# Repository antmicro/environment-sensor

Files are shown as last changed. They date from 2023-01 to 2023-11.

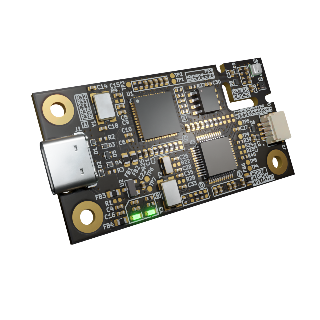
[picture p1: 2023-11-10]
assets/previews/leftT_thumbnail.png

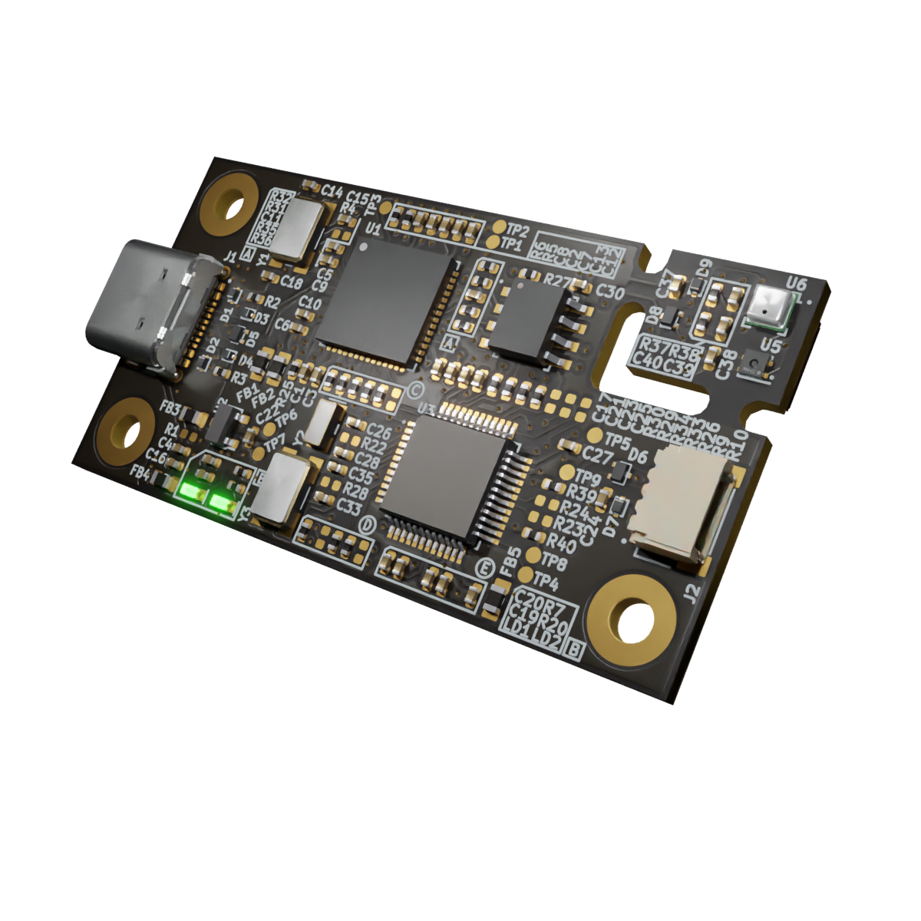
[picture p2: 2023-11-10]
assets/previews/rightT.webp

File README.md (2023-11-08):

# Environment sensor board

Copyright (c) 2023 [Antmicro](https://www.antmicro.com)

Visualization

## Overview

This project contains open hardware design files for an environment sensor board with temperature, pressure and humidity sensors.
These sensors are placed on a separated island in the PCB corner, which can be easily broken out from the main board and connected to it via provided connectors with a cable.
The design files were prepared in KiCad 6.x.

## Key features

* 50.00 mm X 26.50 mm PCB size
* USB-C Connector for data and power
* STM32G474CET6 host MCU
* 128kB external FeRAM 
* FTDI FT4232H USB - JTAG/I2C/UART converter
* SHT45 temperature + humidity sensor:

	* Typ. relative humidity accuracy ±1% RH
	* Operating relative humidity range 0 - 100% RH
	* Typ. temperature accuracy ±0.1 °C
	* Operating temperature range (-40) - (+125) °C
	
* BME280 temperature + humidity + pressure sensor:
	* Typ. relative humidity accuracy ±3% RH
	* Operating relative humidity range 10 - 100% RH
	* Typ. temperature accuracy ±1 °C
	* Operating temperature range (-40) - (+85) °C
	* Typ. pressure accuracy ±1 hPa
	* Operating pressure range 300 - 1100 hPa
	
* I2C connectors
* RTC battery backup

## I2C Address map (7-bit)
* FeRAM: 0x50 + A16 (optional)
* SHT45: 0x44
* BME280: 0x76

## Project structure

The main directory contains KiCad PCB project files, a LICENSE, and a README.
The remaining files are stored in the following directories:

* `img` - contains graphics for this README
* `assets` - contains visual assets for showcasing this design on [Open Hardware Portal](https://openhardware.antmicro.com)

## Licensing

This project is published under the [Apache-2.0](LICENSE) license.

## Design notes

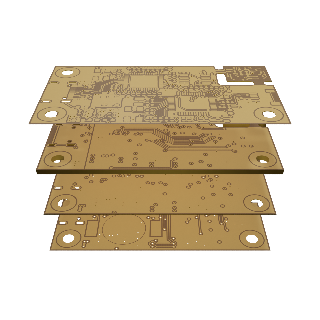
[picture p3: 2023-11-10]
assets/previews/layer1_thumbnail.webp

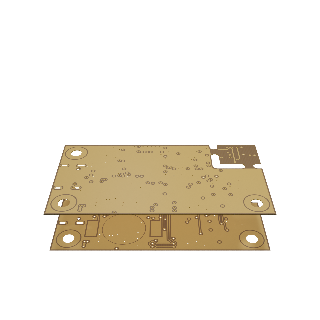
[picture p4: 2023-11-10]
assets/previews/layer3_thumbnail.webp

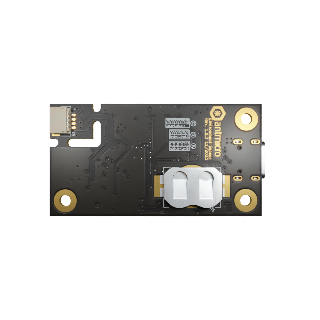
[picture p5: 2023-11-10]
assets/previews/orthoB_thumbnail.webp

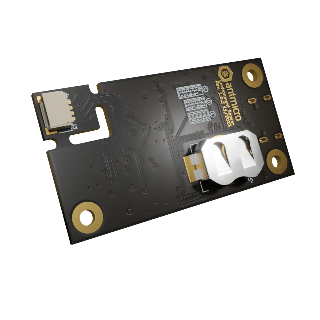
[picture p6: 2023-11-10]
assets/previews/leftB_thumbnail.png

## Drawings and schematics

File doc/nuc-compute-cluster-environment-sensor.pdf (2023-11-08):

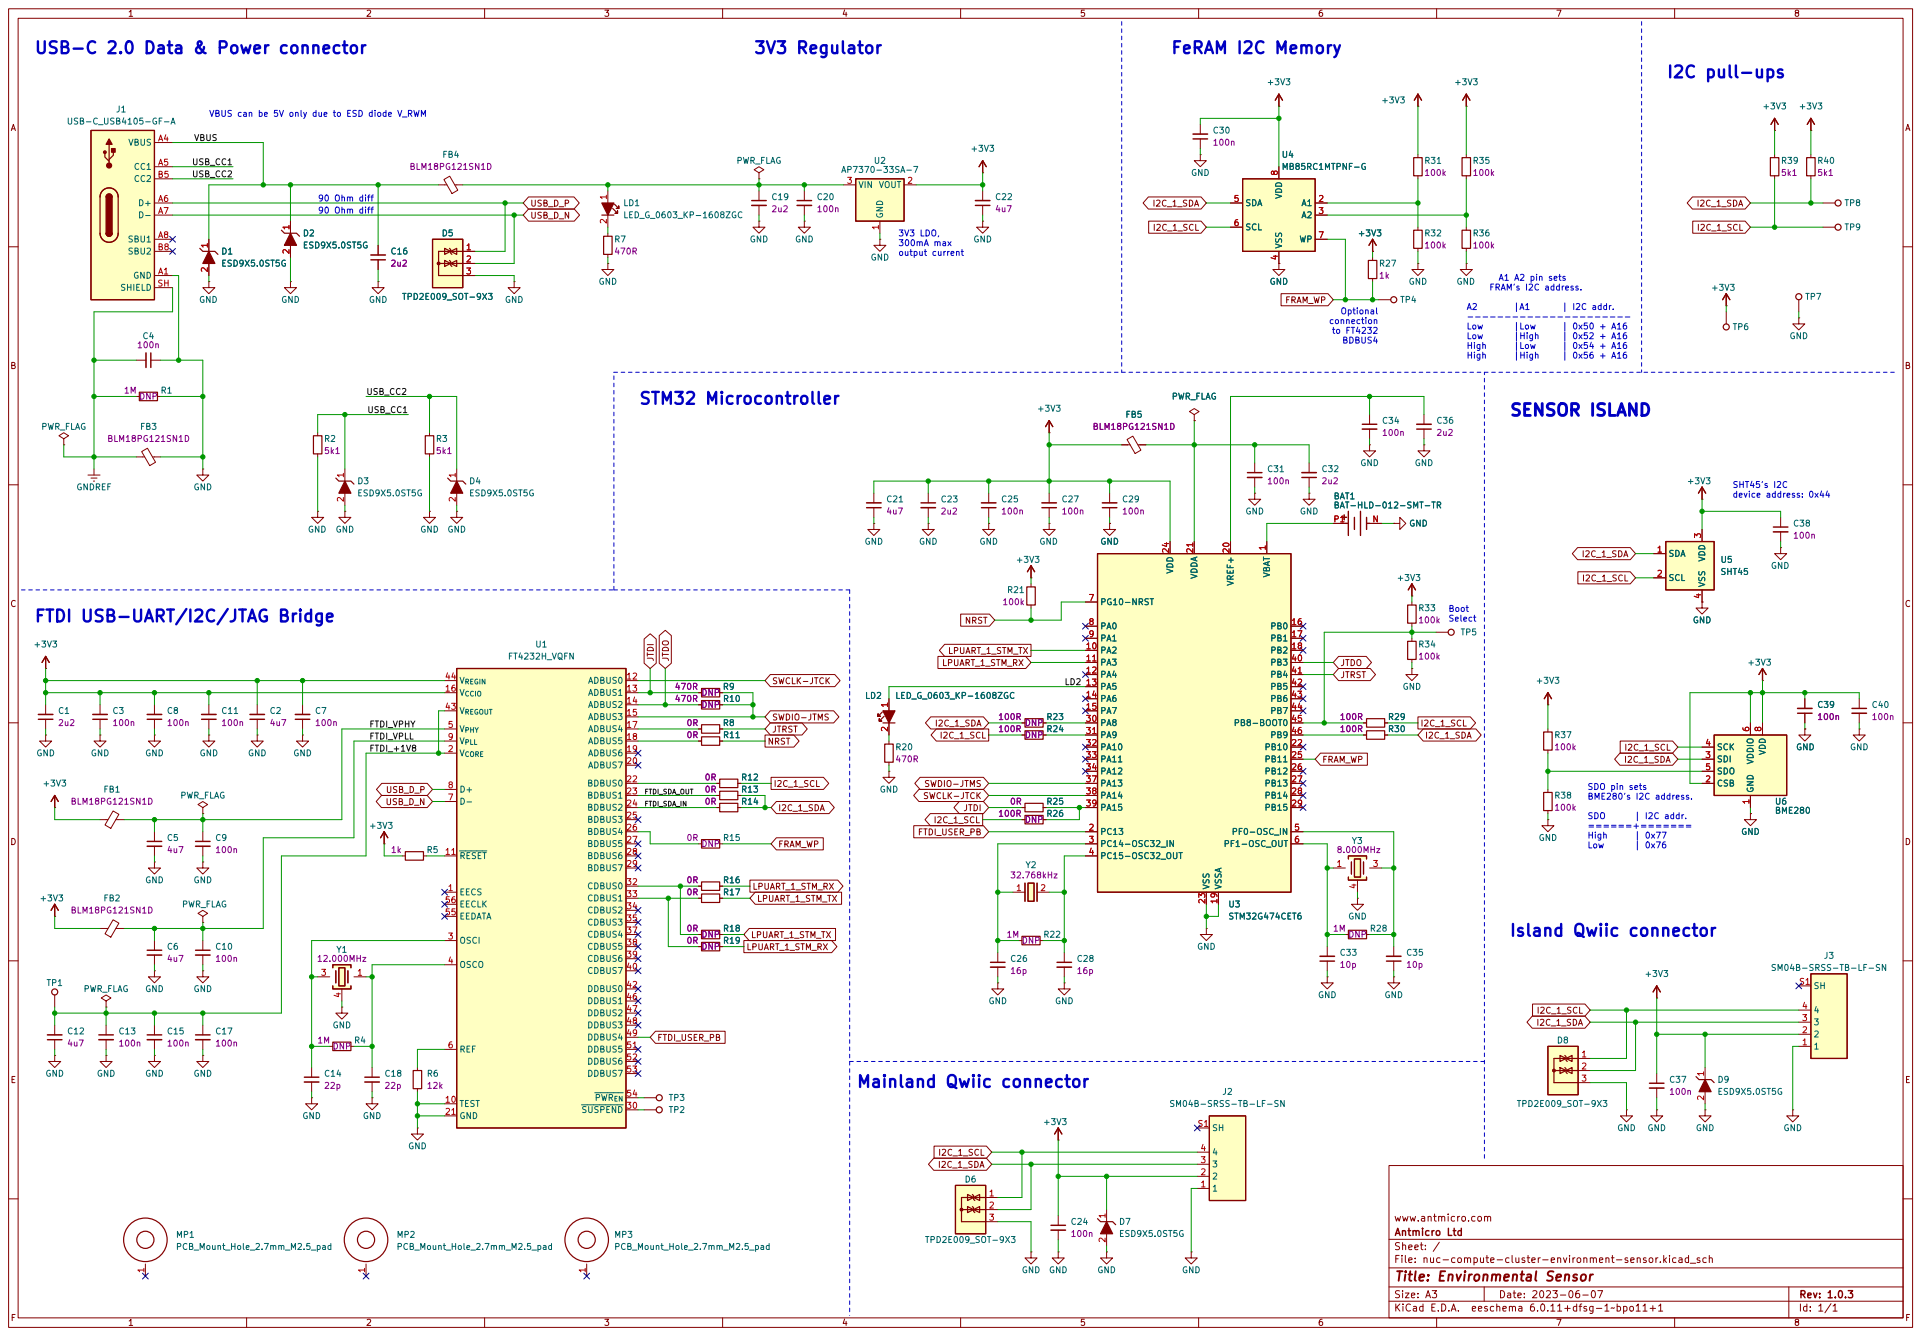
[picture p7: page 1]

VBUS can be 5V only due to ESD diode V_RWM

BAT1 BAT-HLD-012-SMT-TR

J3 SM04B-SRSS-TB-LF-SN

J2 SM04B-SRSS-TB-LF-SN

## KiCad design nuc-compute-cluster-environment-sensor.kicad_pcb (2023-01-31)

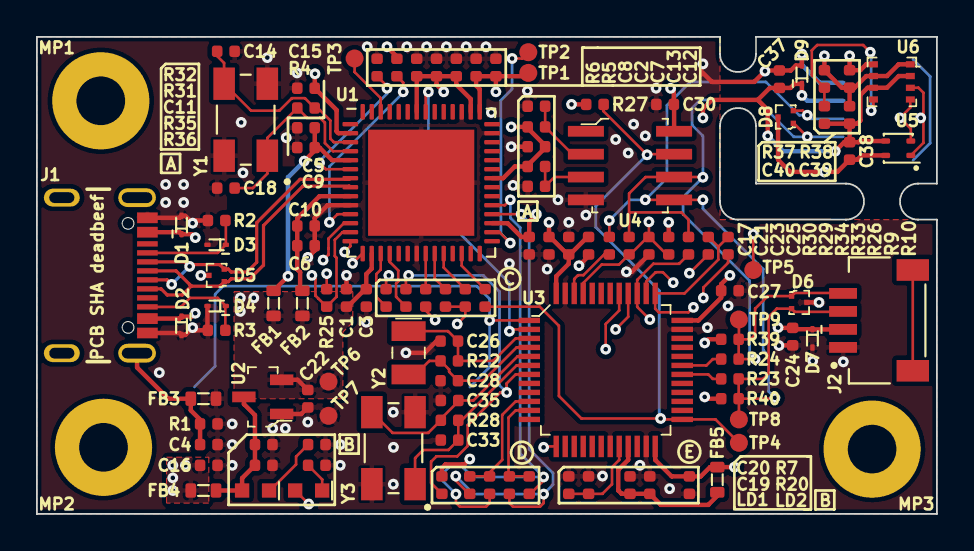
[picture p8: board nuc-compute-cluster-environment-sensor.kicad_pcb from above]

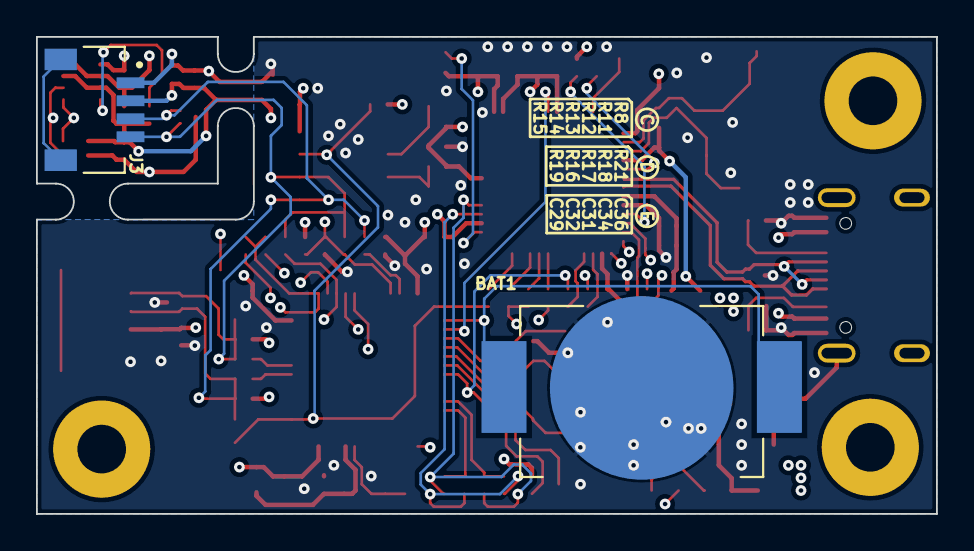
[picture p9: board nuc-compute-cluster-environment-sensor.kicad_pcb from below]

Board: 4 copper layers, 50.0 x 26.5 mm, 121 parts (2 on the bottom side), 56 nets.

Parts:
BAT1: BAT-HLD-012-SMT-TR; BAT_BAT-HLD-012-SMT-TR
C1, C16, C19, C23, C32, C36: C_2u2_0402; 0402-cap
C2, C5, C6, C12, C21, C22: C_4u7_0402; 0402-cap
C3, C4, C7, C8, C9, C10, C11, C13, C15, C17, C20, C24, C25, C27, C29, C30, C31, C34, C37, C38, C39, C40: C_100n_0402; 0402-cap
C14, C18: C_22p_0402; 0402-cap
C26, C28: C_16p_0402; 0402-res
C33, C35: C_10p_0402; 0402-cap
D1, D2, D3, D4, D7, D9: ESD9X5.0ST5G; SOD-923
D5, D6, D8: TPD2E009; SOT-723
FB1, FB2, FB3, FB4, FB5: BLM18PG121SN1D; 0603-res
J1: USB4105-GF-A; GCT_USB4105-GF-A
J2, J3: SM04B-SRSS-TB-LF-SN
LD1, LD2: LG_L29K-G2J1-24-Z; LED_0603
MP1, MP2, MP3: PCB_Mount_Hole_2.7mm_M2.5_pad; mounting-hole-2.7mm-M2.5-Pad
R1, R4, R22, R28: R_1M0_0402; 0402-res
R2, R3, R39, R40: R_5k1_0402; 0402-res
R5, R27: R_1k_0402; 0402-res
R6: R_12k_0402; 0402-res
R7, R9, R10, R20: R_470R_0402; 0402-res
R8, R11, R12, R13, R14, R15, R16, R17, R18, R19, R25: R_0R_0402; 0402-res
R21, R31, R32, R33, R34, R35, R36, R37, R38: R_100k_0402; 0402-res
R23, R24, R26, R29, R30: R_100R_0402; 0402-res
TP1, TP2, TP3, TP4, TP5, TP6, TP7, TP8, TP9: TP_SMD1MM; Testpoint_smd_1mm
U1: FT4232H-56Q; QFN-56-1EP_8x8mm_P0.5mm_EP5.5.9x5.9mm
U2: AP7370-33SA-7; SOT-23-3
U3: STM32G474CET6; LQFP-48_B7x7mm_P0.5mm_0.20mmPadPadClearance_Pad0.30x1.20mm
U4: MB85RC1MTPNF-G; SOIC-8_W3.9mm
U5: SHT45; Sensirion_DFN-4-1.5x1.5x0.5mm_P0.8mm
U6: BME280; Pressure_Sensor_LGA-8_2.5x2.5mm_BME280
Y1: ABM3B-12.000MHZ-B2-T; ABM3B
Y2: ECS-_327-12_5-34B-TR; SMD-2_3.2x1.5mm
Y3: ABM3B-8.000MHZ-10-1-U-T; ABM3B

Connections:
+3V3: C1.1, C2.1, C3.1, C7.1, C8.1, C11.1, C21.1, C22.1, C23.1, C24.2, C25.2, C27.2, C29.2, C30.2, C37.2, C38.2, C39.2, C40.2, D7.1, D9.1, FB1.1, FB2.1, FB5.2, J2.2, J3.2, R5.1, R21.2, R27.2, R31.2, R33.2, R35.2, R37.2, R39.2, R40.2, TP6.1, U1.16 (VCCIO), U1.36 (VCCIO), U1.44 (VREGIN), U1.50 (VCCIO), U2.2 (VOUT), U3.24 (VDD), U3.36 (VDD), U3.48 (VDD), U4.8 (VDD), U5.3 (VDD), U6.2 (CSB), U6.6 (VDDIO), U6.8 (VDD)
/FRAM_WP: R15.2, R27.1, TP4.1, U3.25 (PB11), U4.7 (WP)
/FTDI_+1V8: C12.1, C13.1, C15.1, C17.1, TP1.1, U1.2 (VCORE), U1.31 (VCORE), U1.43 (VREGOUT)
/FTDI_SDA_IN: R14.1, U1.24 (BDBUS2)
/FTDI_SDA_OUT: R13.1, U1.23 (BDBUS1)
/FTDI_USER_PB: U1.49 (DDBUS4), U3.2 (PC13)
/FTDI_VPHY: C5.1, C9.1, FB1.2, U1.5 (VPHY)
/FTDI_VPLL: C6.1, C10.1, FB2.2, U1.9 (VPLL)
/LD2: LD2.1, U3.13 (PA5)
/USB_CC1: D3.1, J1.A5 (CC1), R2.2
/USB_CC2: D4.1, J1.B5 (CC2), R3.2
/USB_D_N: D5.2 (IO2), J1.A7 (D-), J1.B7 (D-), U1.7 (DM)
/USB_D_P: D5.1 (IO1), J1.A6 (D+), J1.B6 (D+), U1.8 (DP)
/VBUS: C16.1, D1.1, D2.1, FB4.2, J1.A4 (VBUS), J1.A9 (VBUS), J1.B4 (VBUS), J1.B9 (VBUS)
GND: BAT1.N, C1.2, C2.2, C3.2, C4.2, C5.2, C6.2, C7.2, C8.2, C9.2, C10.2, C11.2, C12.2, C13.2, C14.1, C15.2, C16.2, C17.2, C18.1, C19.2, C20.2, C21.2, C22.2, C23.2, C24.1, C25.1, C26.1, C27.1, C28.1, C29.1, C30.1, C31.1, C32.2, C33.1, C34.1, C35.1, C36.2, C37.1, C38.1, C39.1, C40.1, D1.2, D2.2, D3.2, D4.2, D5.3 (GND), D6.3 (GND), D7.2, D8.3 (GND), D9.2, FB3.1, J1.A1 (GND), J1.A12 (GND), J1.B1 (GND), J1.B12 (GND), J2.1, J3.1, R1.2, R2.1, R3.1, R6.1, R7.1, R20.1, R32.1, R34.1, R36.1, R38.1, TP7.1, U1.10 (TEST), U1.21 (GND), U1.41 (GND), U1.45 (GND), U1.57 (GND), U2.1 (GND), U3.19 (VSSA), U3.23 (VSS), U3.35 (VSS), U3.47 (VSS), U4.4 (VSS), U5.4 (VSS), U6.1 (GND), U6.7 (GND), Y1.2, Y1.4, Y3.2, Y3.4
GNDREF: C4.1, FB3.2, J1.S1 (SHIELD), R1.1
I2C_1_SCL: D6.1 (IO1), D8.1 (IO1), J2.4, J3.4, R12.2, R24.2, R26.2, R29.2, R39.1, TP9.1, U4.6 (SCL), U5.2 (SCL), U6.4 (SCK)
I2C_1_SDA: D6.2 (IO2), D8.2 (IO2), J2.3, J3.3, R13.2, R14.2, R23.2, R30.2, R40.1, TP8.1, U4.5 (SDA), U5.1 (SDA), U6.3 (SDI)
JTDI: R9.2, R25.1, U1.13 (ADBUS1)
JTDO: R10.2, U1.14 (ADBUS2), U3.40 (PB3)
JTRST: R8.2, U3.41 (PB4)
LPUART_1_STM_RX: R16.2, R19.2, U3.11 (PA3)
LPUART_1_STM_TX: R17.2, R18.2, U3.10 (PA2)
NRST: R11.2, R21.1, U3.7 (PG10-NRST)
unnamed: BAT1.P, U3.1 (VBAT)
unnamed: C14.2, R4.2, U1.3 (OSCI), Y1.3
unnamed: C18.2, R4.1, U1.4 (OSCO), Y1.1
unnamed: C19.1, C20.1, FB4.1, LD1.1, U2.3 (VIN)
unnamed: C26.2, R22.1, U3.3 (PC14-OSC32_IN), Y2.1
unnamed: C28.2, R22.2, U3.4 (PC15-OSC32_OUT), Y2.2
unnamed: C31.2, C32.1, FB5.1, U3.21 (VDDA)
unnamed: C33.2, R28.1, U3.6 (PF1-OSC_OUT), Y3.1
unnamed: C34.2, C36.1, U3.20 (VREF+)
unnamed: C35.2, R28.2, U3.5 (PF0-OSC_IN), Y3.3
unnamed: LD1.2, R7.2
unnamed: LD2.2, R20.2
unnamed: R5.2, U1.11 (RESET)
unnamed: R6.2, U1.6 (REF)
unnamed: R8.1, U1.17 (ADBUS4)
unnamed: R11.1, U1.18 (ADBUS5)
unnamed: R12.1, U1.22 (BDBUS0)
unnamed: R15.1, U1.26 (BDBUS4)
unnamed: R16.1, R18.1, U1.32 (CDBUS0)
unnamed: R17.1, R19.1, U1.33 (CDBUS1)
unnamed: R23.1, U3.30 (PA8)
unnamed: R24.1, U3.31 (PA9)
unnamed: R25.2, R26.1, U3.39 (PA15)
unnamed: R29.1, R33.1, R34.2, TP5.1, U3.45 (PB8-BOOT0)
unnamed: R30.1, U3.46 (PB9)
unnamed: R31.1, R32.2, U4.2 (A1)
unnamed: R35.1, R36.2, U4.3 (A2)
unnamed: R37.1, R38.2, U6.5 (SDO)
unnamed: TP2.1, U1.30 (SUSPEND)
unnamed: TP3.1, U1.54 (PWREN)
SWCLK-JTCK: U1.12 (ADBUS0), U3.38 (PA14)
SWDIO-JTMS: R9.1, R10.1, U1.15 (ADBUS3), U3.37 (PA13)

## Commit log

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2022-11-24 [#39176] SCH: Add USB-C input cicuitry, FT4232H-56Q, STM32G474Rx ICs
    [antmicro-env-sensor-logger.kicad_sch]
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2022-11-29 [#39176] Rename KiCad project to fit repository name
    [nuc-compute-cluster-environment-sensor.kicad_pcb, nuc-compute-cluster-environment-sensor.kicad_sch]
2022-12-08 [#39176] SCH: Add SHT45 & BME280 environment sensors
    [nuc-compute-cluster-environment-sensor.kicad_sch]
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2022-12-08 [#39176] SCH: Add SM04B-SRSS-TB-LF-SN QWIIC I²C expansion connector
    [nuc-compute-cluster-environment-sensor.kicad_sch]
2022-12-08 [#39176] SCH: Add 32kHz SMT Crystal Oscillator for Real-Time Clock
    [nuc-compute-cluster-environment-sensor.kicad_sch]
2022-12-09 [#39176] Change USB-C 2.0 connector to GCT USB4105-GF-A for easier manufacturability
    [nuc-compute-cluster-environment-sensor.kicad_sch]
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2022-12-16 [#39832] SCH: Change battery holder to CR1216/CR1225 STM one
    [nuc-compute-cluster-environment-sensor.kicad_sch]
2022-12-23 [#39832] SCH: Wire up 32kHz RTC crystal to MCU
    [nuc-compute-cluster-environment-sensor.kicad_sch]
2022-12-23 [#39832] SCH: Add an DNP parallel 1M resistor to 32kHz RTC crystal for eventual oscillation stabilization
    [nuc-compute-cluster-environment-sensor.kicad_sch]
2022-12-23 [#39832] SCH: Add & wire up 8MH main MCU ceramic oscillator
    [nuc-compute-cluster-environment-sensor.kicad_sch]
2022-12-23 [#39832] SCH: Adjust 8MHz oscillator load capacitors
    [nuc-compute-cluster-environment-sensor.kicad_sch]
2022-12-23 [#39832] SCH: Complete circuitry near USB-C & 3V3 LDO, connect BAT to MCU
    Complete changelog:
    - Connect battery to MCU,
    - add more ESD protection to USB-C,
    - rearrange schematic,
    - increase filtering caps on USB-C input to 2x2u2,
    - change caps to 0402 where possible,
    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
    [nuc-compute-cluster-environment-sensor.kicad_sch]
2022-12-23 [#39832] SCH: Add parallel 100n cap and 1M resistor to connect USB-C GND & Shield, as DNP for now
    [nuc-compute-cluster-environment-sensor.kicad_sch]
2022-12-23 [#39832] SCH: Wire up STM32 according to Default Zephyr Peripheral Mapping & datasheet, wire up SHT45 & more
    Default Zephyr Peripheral Mapping listed at:
    https://docs.zephyrproject.org/3.1.0/boards/arm/nucleo_g474re/doc/index.html#default-zephyr-peripheral-mapping
    Full changelog:
    - To STM32: Wire up VDD & VDDA, I2C_1, JTAG/SWD, LPUART_1, NRST as global labels
    - Add LD2 Zephyr User LED circuit to STM32
    - Add 100n decoupling capacitors
    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
    [nuc-compute-cluster-environment-sensor.kicad_sch]
2022-12-23 [#39832] SCH: Wire up the two QWIIC connections, wire up BME280, create "Sensor Island" section
    [nuc-compute-cluster-environment-sensor.kicad_sch]
2022-12-23 [#39832] SCH: Begin wiring up FT4232H-56Q,
    - Change some decoupling caps from 2u2 to 4u7 due to FTDI datasheet requirements
    - Wire up the FT4232H-56Q power, oscillator & some input pins
    - Add 12MHz ceramic oscillator with accompanying elements
    - Add a DNP ferrite bead inbetween USB-C GND and SHIELD
    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
    [nuc-compute-cluster-environment-sensor.kicad_sch]
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2022-12-27 SCH: Update BME280 & SHT45 symbols to fix datasheet link
    [nuc-compute-cluster-environment-sensor.kicad_sch]
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2022-12-27 [#39832] SCH: Add ESD protection diodes for 3V3 pins in QWIIC connectors, change most pull-ups to 100k
    [nuc-compute-cluster-environment-sensor.kicad_sch]
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2022-12-27 [#39832] SCH: Fix typos in I2C labels
    [nuc-compute-cluster-environment-sensor.kicad_sch]
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2022-12-27 [#39832] SCH: Fix FT4232H I2C connection, move FRAM Write Protect to BDBUS4
    [nuc-compute-cluster-environment-sensor.kicad_sch]
2022-12-27 [#39832] SCH: Fix USB_CC - ESD protetction TVSes miswiring
    [nuc-compute-cluster-environment-sensor.kicad_sch]
2022-12-27 [#39832] SCH: Fix missing pin 20(VREF+) on STM32, add decoupling caps for it
    [nuc-compute-cluster-environment-sensor.kicad_sch]
2022-12-27 [#39832] SCH: Move I2C series protection resistors, add level setting DNP resistors onto PB8/BOOT0
    - Remove 100R series protection resistors from Qwiic connectors
    - Add a single pair of 100R series protection resistors to STM32's I2C pins
    - Add a DNP 100k pull-up & 100k pull-down for STM32's BOOT0 pin
    - Add a "Boot Select" text note to above setters
    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
    [nuc-compute-cluster-environment-sensor.kicad_sch]
2022-12-27 [#39832] SCH: Add optional alternate I2C bus connections to STM32 thru DNP resistors
    - Add optional I2C_1_SCL connection on PA15 (JTDI)
    - Add optional I2C_1 bus connection on I2C2 output pair PA8 & PA9
    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
    [nuc-compute-cluster-environment-sensor.kicad_sch]
2022-12-27 [#39832] SCH: Change address setting PU/PD resistors to 100k for BOM unification
    [nuc-compute-cluster-environment-sensor.kicad_sch]
2022-12-27 [#39832] SCH: Rearranged components on 3V3 LDO input, removed redundant 0R from there
    [nuc-compute-cluster-environment-sensor.kicad_sch]
2022-12-27 [#39832] SCH: Change I2C pull-ups to 5k1 for BOM unification & better I2C 400kHz mode support
    [nuc-compute-cluster-environment-sensor.kicad_sch]
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2022-12-27 [#39832] SCH: Fix UART TX/RX swap, add 0Rs just in case
    [nuc-compute-cluster-environment-sensor.kicad_sch]
2022-12-27 [#39832] SCH: Replace LDO with AP7370-33SA-7 for 300mA max 3V3 bus current
    [nuc-compute-cluster-environment-sensor.kicad_sch]
2022-12-27 [#39832] SCH: Wire FRAM's Write Protect to unused PB11, mark unused STM32 pins with No-Connect flags.
    [nuc-compute-cluster-environment-sensor.kicad_sch]
2022-12-27 [#39832] SCH: Wire FTDI's DBUS4 to STM32's PC13 as Zephyr's default User_PB
    [nuc-compute-cluster-environment-sensor.kicad_sch]
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2022-12-27 [#39832] SCH: Set revision to 1.0.0, update date & generate schematic PDF
    [nuc-compute-cluster-environment-sensor.kicad_sch]
2023-01-03 Finished schematic review, corrected decoupling caps, initial component placement done
    [nuc-compute-cluster-environment-sensor.kicad_pcb, nuc-compute-cluster-environment-sensor.kicad_sch]
2023-01-03 Started to route signals to closest passive components to seek for possible placement optimization
    [nuc-compute-cluster-environment-sensor.kicad_pcb, nuc-compute-cluster-environment-sensor.kicad_sch]
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2023-01-05 New component placement, FTDI and related passive components moved to bottom layer
    [nuc-compute-cluster-environment-sensor.kicad_pcb]
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2023-01-09 New component placement after review, all components moved to top layer except battery and connector
    [nuc-compute-cluster-environment-sensor.kicad_pcb, nuc-compute-cluster-environment-sensor.kicad_sch]
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2023-01-10 Designators' placement finished, DRC performed with no issues found
    [nuc-compute-cluster-environment-sensor.kicad_pcb]
2023-01-10 Added 1k pullup on FRAM write protection pin, 470R serial resistors added on SWDIO and SWCLK, keepout zones for GND added around USB
    [nuc-compute-cluster-environment-sensor.kicad_pcb, nuc-compute-cluster-environment-sensor.kicad_sch]
2023-01-10 Clearance on filled zones increased to 0,25mm, small tweaks added on layout
    [nuc-compute-cluster-environment-sensor.kicad_pcb]
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2023-01-11 Corrected MPN and values on schematic for C13 C15 C17
    [nuc-compute-cluster-environment-sensor.kicad_sch]
2023-01-12 Small tweaks on schematic comments and PCB silkscreen, exported wrl models, README finished
    [nuc-compute-cluster-environment-sensor.kicad_pcb, nuc-compute-cluster-environment-sensor.kicad_sch]
2023-01-31 Fixed connection of SWD/JTAG configuration resistors
    [nuc-compute-cluster-environment-sensor.kicad_pcb, nuc-compute-cluster-environment-sensor.kicad_sch]
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2023-05-24 Preliminaty PCB correction
2023-05-25 PCB fixes
    [nuc-compute-cluster-environment-sensor.kicad_sch]
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2023-05-25 Fix MB85RC1MTPNF-G footprint
    [nuc-compute-cluster-environment-sensor.kicad_sch]
2023-05-26 Fix gnd path
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2023-10-20 [#47270] Fixed ERC warnings
    [nuc-compute-cluster-environment-sensor.kicad_sch]
2023-10-20 [#47270] Fix silkscreen overlaps
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

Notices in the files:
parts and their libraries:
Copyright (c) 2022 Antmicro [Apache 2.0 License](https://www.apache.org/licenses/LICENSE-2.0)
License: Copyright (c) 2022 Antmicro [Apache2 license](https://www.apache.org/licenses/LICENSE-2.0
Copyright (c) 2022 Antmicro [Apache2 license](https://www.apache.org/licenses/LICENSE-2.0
